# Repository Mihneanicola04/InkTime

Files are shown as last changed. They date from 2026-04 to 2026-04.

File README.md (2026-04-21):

# InkTime - Smartwatch Open Source

**InkTime** este un start-up dedicat crearii unui smartwatch accesibil si open-source. Acest repository contine documentatia tehnica, fisierele de proiectare hardware (schematica si layout PCB), fisierele de productie si modelele 3D necesare pentru fabricarea dispozitivului.

## 1. Diagrama Bloc
Diagrama de mai jos ilustreaza arhitectura sistemului, evidentiind interconexiunile dintre microcontrolerul nRF52840 si modulele periferice (Display, IMU, Alimentare).

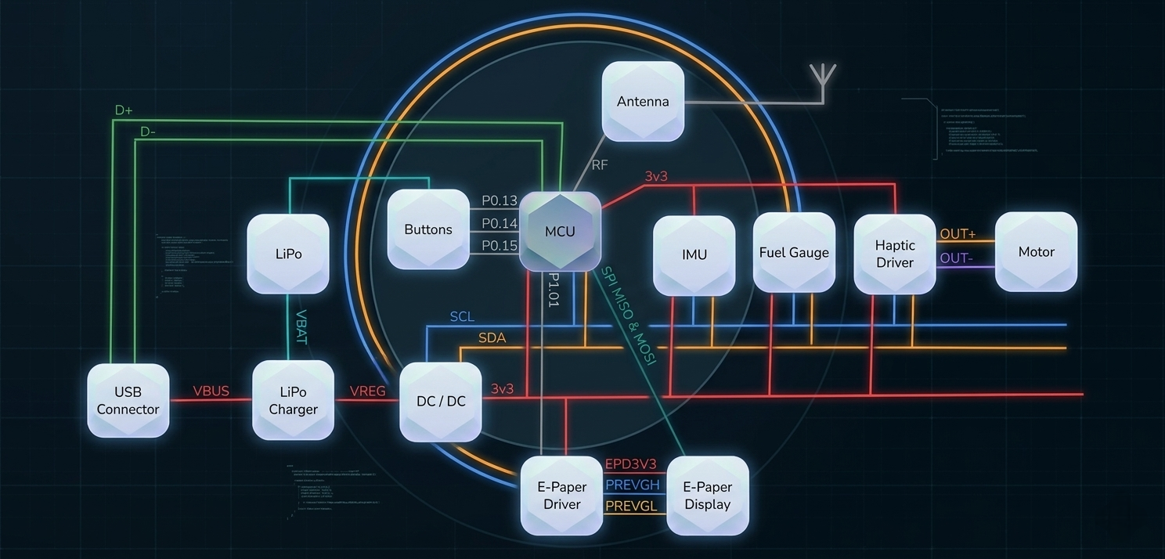
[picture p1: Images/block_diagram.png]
Diagrama Bloc
 

---

## 2. Bill of Materials (BOM)
Toate componentele au fost selectate pentru a fi compatibile cu asamblarea automata prin JLC PCB.

| Componenta / Modul | Descriere | Link Achizitie (JLC Parts) | Datasheet |
| :--- | :--- | :--- | :--- |
| **nRF52840** | SoC Bluetooth Low Energy | [Link JLC](https://jlcpcb.com/parts) | (https://infocenter.nordicsemi.com/) |
| **Display E-Paper** | Ecran cu consum redus | [Link JLC](https://jlcpcb.com/parts) |(https://jlcpcb.com/parts) |
| **Baterie Li-Po** | 3.7V, conectare directa pe pad-uri | [Link JLC](https://jlcpcb.com/parts) |(https://jlcpcb.com/parts) |
| **Senzor IMU** | Senzor de miscare (Accel/Gyro) | [Link JLC](https://jlcpcb.com/parts) | (https://jlcpcb.com/parts) |
| **Butoane SMD** | Tip 0201/0402 conform cerintelor | [Link JLC](https://jlcpcb.com/parts) |(https://jlcpcb.com/parts) |
| **Condensatoare** | 100nF (0201) / >100nF (0402) | [Link JLC](https://jlcpcb.com/parts) |(https://jlcpcb.com/parts) |

---

## 3. Functionalitate Hardware si Design

### Detalii Tehnice
* **Unitate de procesare:** nRF52840, ales pentru integrarea BLE si eficienta energetica.
* **Interfete de comunicatie:**
    * **SPI:** Utilizat pentru controlul ecranului e-paper pentru rate de refresh optime.
    * **I2C:** Utilizat pentru senzorul IMU si managementul bateriei.
* **Managementul energiei:** PCB-ul include circuite de protectie pentru bateria Li-Po. Consumul a fost optimizat prin utilizarea condensatoarelor de decuplare de 100nF amplasate imediat langa pinii de alimentare. Autonomia a fost calculata avand in vedere starea de sleep si timpii activi ai procesorului si display-ului.
* **PCB Design:** * Grosime PCB: **1mm**.
    * Trasee de putere (VCC, 3V3): **0.3mm**.
    * Trasee de date: **0.15mm**.
    * Plan de masa: Prezent pe ambele straturi (Top/Bottom) cu **Via Stitching** pentru integritatea semnalului radio.

### Mapare Pini nRF52840
| Pin nRF52840 | Componenta | Functie / Justificare |
| :--- | :--- | :--- |
| **P0.xx** | SPI CLK | Clock pentru ecranul e-paper |
| **P0.yy** | I2C SDA | Date pentru senzorul IMU |
| **P0.zz** | Buton 1 | Intrare digitala cu pull-up intern |
| **VBUS** | USB-C | Detectare alimentare si incarcare baterie |

---

## 4. Implementare si Decizii de Proiectare (Design Log)

In cadrul procesului de dezvoltare (EVT/DVT), s-au luat urmatoarele decizii tehnice:
1.  **Amplasare Componente:** Toate componentele au fost plasate pe layer-ul **TOP** pentru a simplifica procesul de fabricatie.
2.  **Antena:** A fost plasata la extremitatea placii, cu planul de masa decupat dedesubt pentru a evita atenuarea semnalului BLE.
3.  **Conectivitate Baterie:** Din ratiuni de spatiu in carcasa, s-a renuntat la conectorul JST, bateria fiind lipita direct pe test pad-urile dedicate.
4.  **Erori Acceptate:** Eroarea DRC "Only INPUT pins on NET ID" a fost ignorata conform specificatiilor, fiind un artefact al bibliotecii de simboluri.
5.  **Mecanica:** Carcasa a fost ajustata in Fusion360 pentru a asigura alinierea perfecta a portului USB-C si a butoanelor fizice.
---

## 5. Structura Repository
* `/Hardware`: Fisiere native Fusion360 (.sch, .brd).
* `/Manufacturing`: Fisiere Gerber, BOM si Pick and Place.
* `/Mechanical`: Modele 3D (STEP/Exploded view) si asamblarea in Fusion360.
* `/Images`: Randari ale produsului finit si ale PCB-ului.
---

## 6   . Licenta
Acest proiect este licentiat sub [Apache License 2.0](LICENSE).

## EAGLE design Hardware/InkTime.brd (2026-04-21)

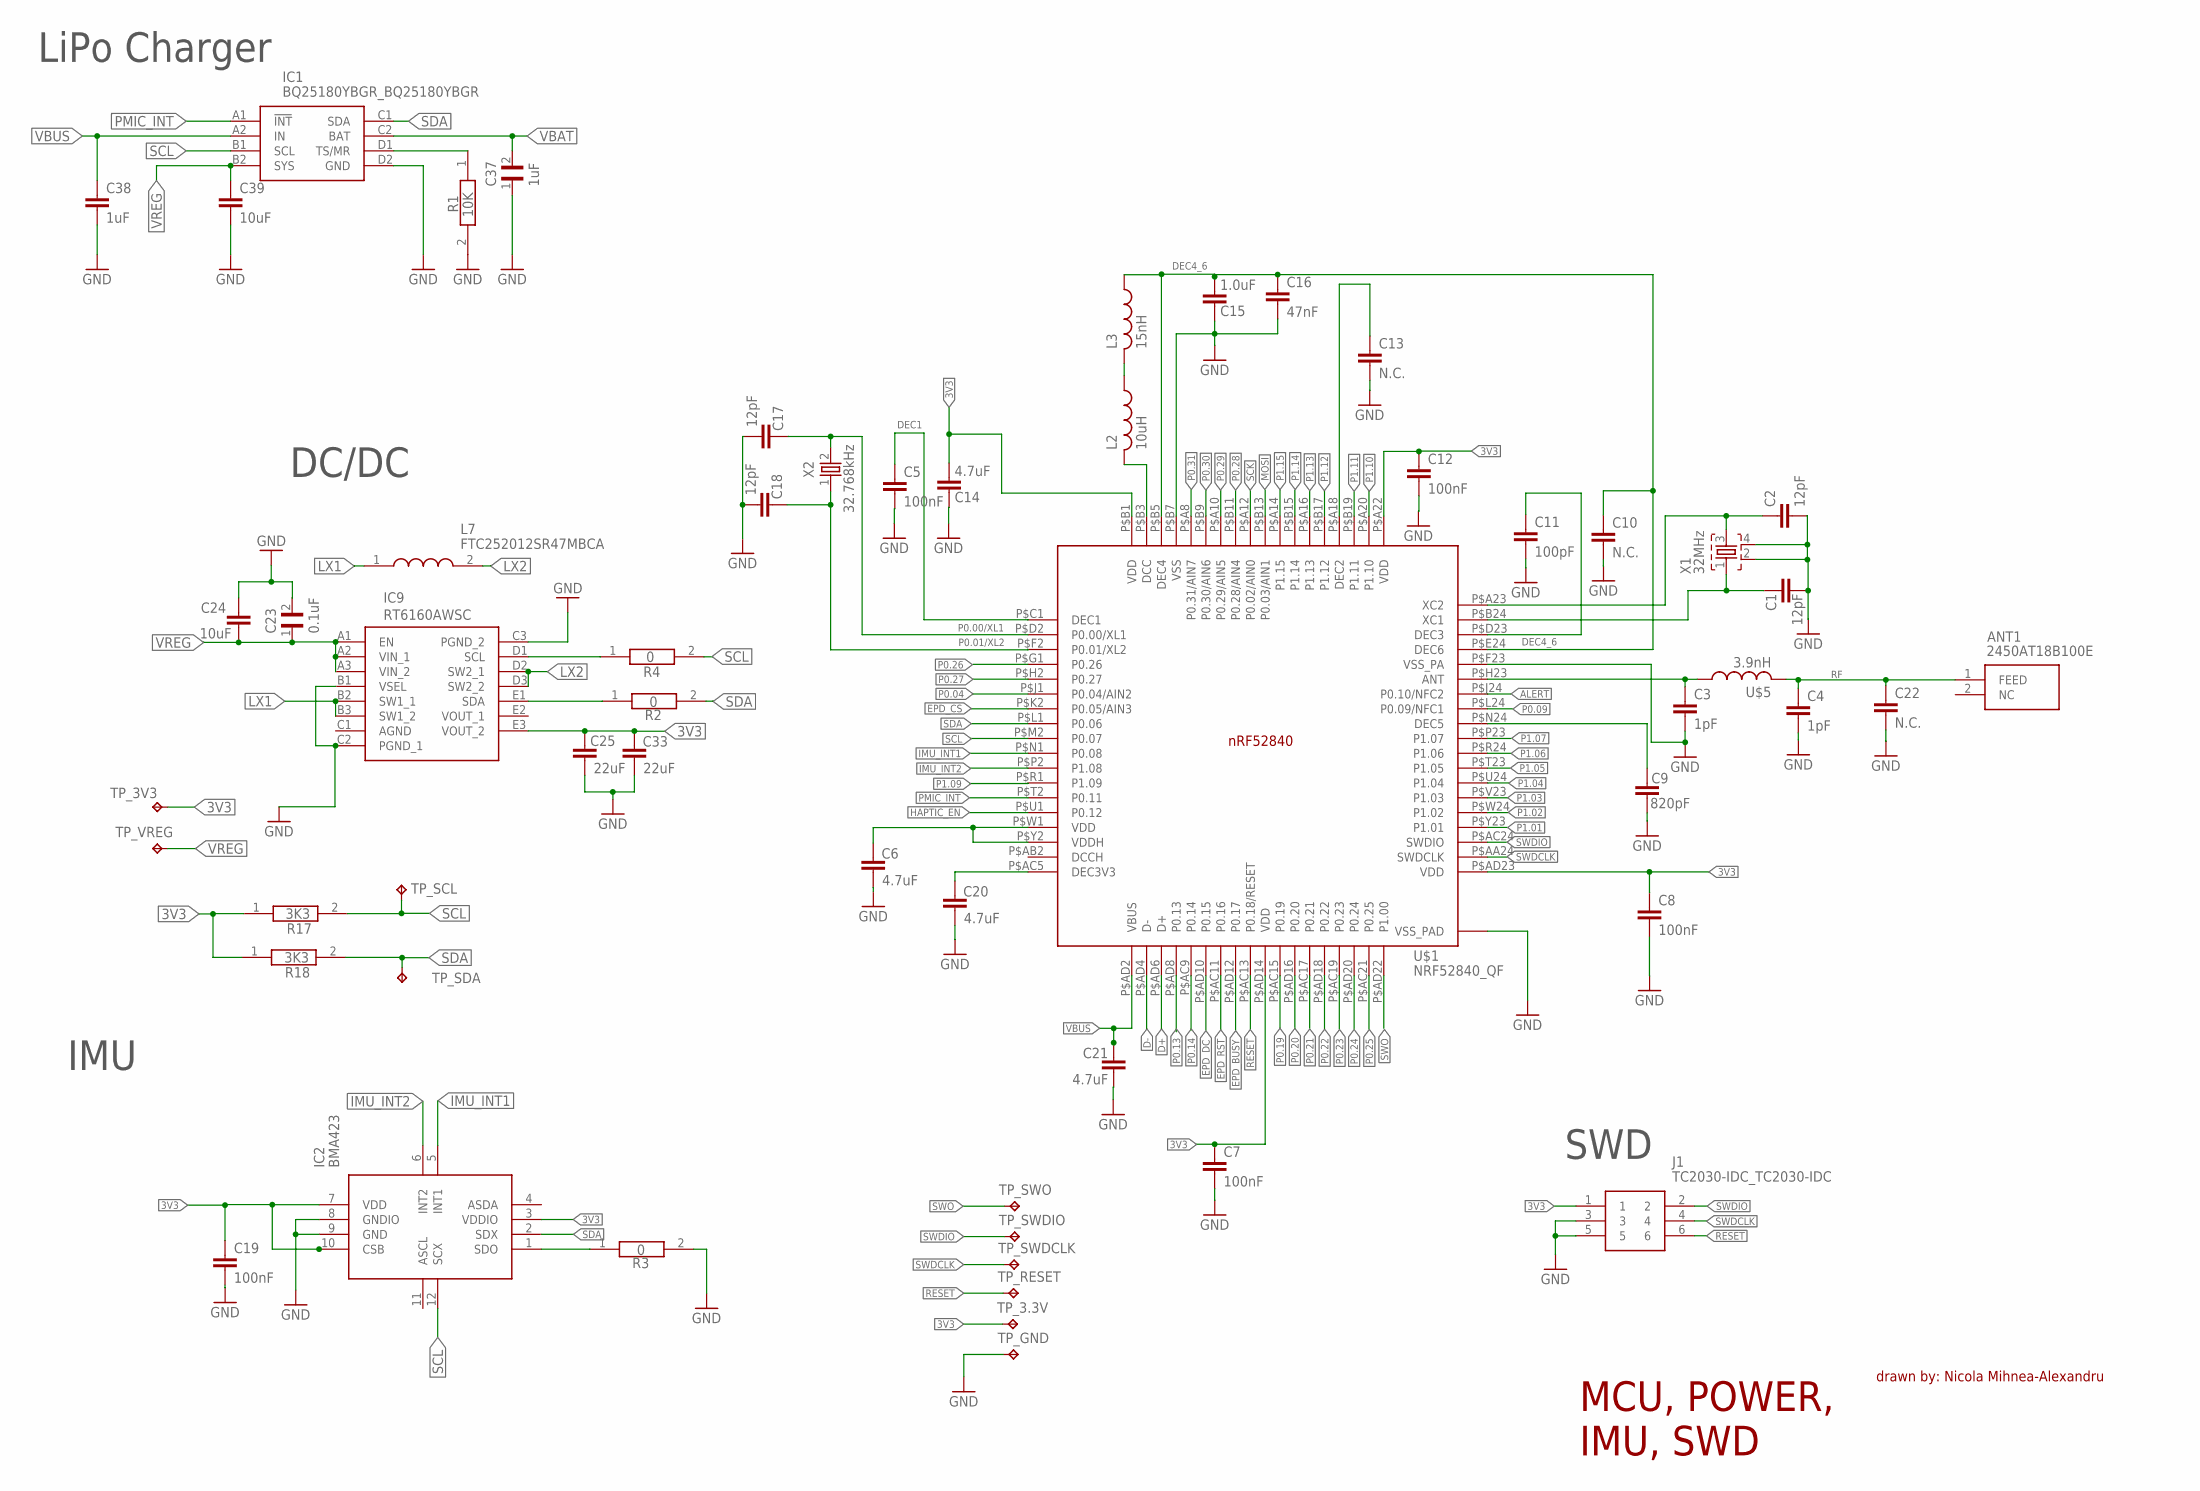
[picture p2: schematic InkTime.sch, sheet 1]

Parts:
ANT1: 2450AT18B100E; 2450AT18B100E_ANTC3216X140N
C1, C2, C17, C18: 12pF; NORDIC_NRF_3_RESC0201_N
C3, C4: 1pF; NORDIC_NRF_3_RESC0201_N
C5, C7, C8, C12, C19: 100nF; NORDIC_NRF_3_RESC0201_N
C6, C14, C20, C21: 4.7uF; NORDIC_NRF_3_RESC0402_N
C9: 820pF; NORDIC_NRF_3_RESC0201_N
C10, C13, C22: N.C.; NORDIC_NRF_3_RESC0201_N
C11: 100pF; NORDIC_NRF_3_RESC0201_N
C15: 1.0uF; NORDIC_NRF_3_RESC0402_N
C16: 47nF; NORDIC_NRF_3_RESC0201_N
C23: 0.1uF; GRM011R60J152KE01L_2_CAPC0201X13N
C24, C39: 10uF; NORDIC_NRF_3_RESC0402_N
C25, C33: 22uF; NORDIC_NRF_3_RESC0402_N
C37: 1uF; GRM011R60J152KE01L_2_CAPC0201X13N
C38: 1uF; NORDIC_NRF_3_RESC0402_N
IC1: BQ25180YBGR_BQ25180YBGR; BQ25180YBGR_BGA8C40P2X4_100X155X50
IC2: BMA423; BMA423_BMA423
IC9: RT6160AWSC; RT6160AWSC_BGA15C40P3X5_140X230X60
J1: TC2030-IDC_TC2030-IDC; TC2030-IDC_TC2030IDC
L2: 10uH; NORDIC_NRF_2_RESC0201_N
L3: 15nH; NORDIC_NRF_2_RESC0201_N
L7: FTC252012SR47MBCA; MLP2016SR47MT0S1_INDC2016X100N
R1: 10K; CPF0201D7K68C1_0201
R2, R3, R4: 0; CPF0201D7K68C1_0201
R17, R18: 3K3; CPF0201D7K68C1_0201
TP_3.3V, TP_3V3: HECTOR_WATCH_1_TPTP20R; HECTOR_WATCH_1_TP20R
TP_GND: HECTOR_WATCH_1_TPTP20R; HECTOR_WATCH_1_TP20R
TP_RESET: HECTOR_WATCH_1_TPTP20R; HECTOR_WATCH_1_TP20R
TP_SCL: HECTOR_WATCH_1_TPTP20R; HECTOR_WATCH_1_TP20R
TP_SDA: HECTOR_WATCH_1_TPTP20R; HECTOR_WATCH_1_TP20R
TP_SWDCLK: HECTOR_WATCH_1_TPTP20R; HECTOR_WATCH_1_TP20R
TP_SWDIO: HECTOR_WATCH_1_TPTP20R; HECTOR_WATCH_1_TP20R
TP_SWO: HECTOR_WATCH_1_TPTP20R; HECTOR_WATCH_1_TP20R
TP_VREG: HECTOR_WATCH_1_TPTP20R; HECTOR_WATCH_1_TP20R
U$1: NRF52840_QF; NORDIC_NRF_4_AQFN50P700X700X85_HS-74N
U$5: 3.9nH; NORDIC_NRF_2_RESC0201_N
X1: 32MHz; NORDIC_NRF_BT-XTAL_2016_N
X2: 32.768kHz; NORDIC_NRF_1_XTAL_3215_N

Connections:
3V3: C7.1, C8.1, C12.1, C14.2, C19.1, C25.1, C33.1, IC2.3 (VDDIO), IC9.E3 (VOUT_2), J1.1, R17.1, R18.1, TP_3.3V.TP, TP_3V3.TP, U$1.P$A22 (VDD), U$1.P$AD14 (VDD), U$1.P$AD23 (VDD), U$1.P$B1 (VDD); also elsewhere on the board
ALERT: U$1.P$J24 (P0.10/NFC2); also elsewhere on the board
D+: U$1.P$AD6 (D+); also elsewhere on the board
D-: U$1.P$AD4 (D-); also elsewhere on the board
DEC1: C5.1, U$1.P$C1 (DEC1)
DEC4_6: C10.1, C15.2, C16.1, L3.1, U$1.P$B5 (DEC4), U$1.P$E24 (DEC6)
EPD_BUSY: U$1.P$AD12 (P0.17); also elsewhere on the board
EPD_CS: U$1.P$K2 (P0.05/AIN3); also elsewhere on the board
EPD_DC: U$1.P$AD10 (P0.15); also elsewhere on the board
EPD_RST: U$1.P$AC11 (P0.16); also elsewhere on the board
GND: C1.2, C2.2, C3.2, C4.2, C5.2, C6.2, C7.2, C8.2, C9.2, C10.2, C11.2, C12.2, C13.2, C14.1, C15.1, C16.2, C17.2, C18.2, C19.2, C20.2, C21.2, C22.2, C23.2, C24.1, C25.2, C33.2, C37.1, C38.2, C39.2, IC1.D2 (GND), IC2.8 (GNDIO), IC2.9 (GND), IC9.B1 (VSEL), IC9.C2 (PGND_1), IC9.C3 (PGND_2), J1.3, J1.5, R1.2, R3.2, TP_GND.TP, U$1.P$74 (VSS_PAD), U$1.P$75 (VSS_PAD), U$1.P$76 (VSS_PAD), U$1.P$77 (VSS_PAD), U$1.P$78 (VSS_PAD), U$1.P$79 (VSS_PAD), U$1.P$80 (VSS_PAD), U$1.P$81 (VSS_PAD), U$1.P$82 (VSS_PAD), U$1.P$83 (VSS_PAD), U$1.P$84 (VSS_PAD), U$1.P$85 (VSS_PAD), U$1.P$86 (VSS_PAD), U$1.P$87 (VSS_PAD), U$1.P$88 (VSS_PAD), U$1.P$89 (VSS_PAD), U$1.P$90 (VSS_PAD), U$1.P$B7 (VSS), U$1.P$F23 (VSS_PA), X1.2, X1.4; also elsewhere on the board
HAPTIC_EN: U$1.P$U1 (P0.12); also elsewhere on the board
IMU_INT1: IC2.5 (INT1), U$1.P$N1 (P0.08)
IMU_INT2: IC2.6 (INT2), U$1.P$P2 (P1.08)
LX1: IC9.B2 (SW1_1), IC9.B3 (SW1_2), L7.1
LX2: IC9.D2 (SW2_1), IC9.D3 (SW2_2), L7.2
MOSI: U$1.P$B13 (P0.03/AIN1); also elsewhere on the board
unnamed: C20.1, U$1.P$AC5 (DEC3V3)
unnamed: IC9.D1 (SCL), R4.1
unnamed: IC9.E1 (SDA), R2.1
unnamed: IC1.D1 (TS/MR), R1.1
unnamed: C6.1, U$1.P$W1 (VDD)
unnamed: IC2.7 (VDD), IC2.10 (CSB)
unnamed: L2.2, U$1.P$B3 (DCC)
unnamed: L2.1, L3.2
unnamed: IC2.1 (SDO), R3.1
unnamed: C11.1, U$1.P$D23 (DEC3)
unnamed: C2.1, U$1.P$A23 (XC2), X1.3
unnamed: C13.1, U$1.P$A18 (DEC2)
unnamed: C1.1, U$1.P$B24 (XC1), X1.1
unnamed: C3.1, U$1.P$H23 (ANT), U$5.1
unnamed: C9.1, U$1.P$N24 (DEC5)
P0.00/XL1: C17.1, U$1.P$D2 (P0.00/XL1), X2.2
P0.01/XL2: C18.1, U$1.P$F2 (P0.01/XL2), X2.1
P0.04: U$1.P$J1 (P0.04/AIN2)
P0.09: U$1.P$L24 (P0.09/NFC1)
P0.13: U$1.P$AD8 (P0.13); also elsewhere on the board
P0.14: U$1.P$AC9 (P0.14); also elsewhere on the board
P0.19: U$1.P$AC15 (P0.19)
P0.20: U$1.P$AD16 (P0.20)
P0.21: U$1.P$AC17 (P0.21)
P0.22: U$1.P$AD18 (P0.22)
P0.23: U$1.P$AC19 (P0.23)
P0.24: U$1.P$AD20 (P0.24)
P0.25: U$1.P$AC21 (P0.25)
P0.26: U$1.P$G1 (P0.26)
P0.27: U$1.P$H2 (P0.27)
P0.28: U$1.P$B11 (P0.28/AIN4)
P0.29: U$1.P$A10 (P0.29/AIN5)
P0.30: U$1.P$B9 (P0.30/AIN6)
P0.31: U$1.P$A8 (P0.31/AIN7)
P1.01: U$1.P$Y23 (P1.01); also elsewhere on the board
P1.02: U$1.P$W24 (P1.02); also elsewhere on the board
P1.03: U$1.P$V23 (P1.03)
P1.04: U$1.P$U24 (P1.04)
P1.05: U$1.P$T23 (P1.05)
P1.06: U$1.P$R24 (P1.06)
P1.07: U$1.P$P23 (P1.07)
P1.09: U$1.P$R1 (P1.09)
P1.10: U$1.P$A20 (P1.10)
P1.11: U$1.P$B19 (P1.11)
P1.12: U$1.P$B17 (P1.12)
P1.13: U$1.P$A16 (P1.13)
P1.14: U$1.P$B15 (P1.14)
P1.15: U$1.P$A14 (P1.15)
PMIC_INT: IC1.A1 (!INT), U$1.P$T2 (P0.11)
RESET: J1.6, TP_RESET.TP, U$1.P$AC13 (P0.18/RESET)
RF: ANT1.1 (FEED), C4.1, C22.1, U$5.2
SCK: U$1.P$A12 (P0.02/AIN0); also elsewhere on the board
SCL: IC1.B1 (SCL), IC2.12 (SCX), R4.2, R17.2, TP_SCL.TP, U$1.P$M2 (P0.07); also elsewhere on the board
SDA: IC1.C1 (SDA), IC2.2 (SDX), R2.2, R18.2, TP_SDA.TP, U$1.P$L1 (P0.06); also elsewhere on the board
SWDCLK: J1.4, TP_SWDCLK.TP, U$1.P$AA24 (SWDCLK)
SWDIO: J1.2, TP_SWDIO.TP, U$1.P$AC24 (SWDIO)
SWO: TP_SWO.TP, U$1.P$AD22 (P1.00)
VBAT: C37.2, IC1.C2 (BAT); also elsewhere on the board
VBUS: C21.1, C38.1, IC1.A2 (IN), U$1.P$AD2 (VBUS); also elsewhere on the board
VREG: C23.1, C24.2, C39.1, IC1.B2 (SYS), IC9.A1 (EN), IC9.A2 (VIN_1), IC9.A3 (VIN_2), TP_VREG.TP

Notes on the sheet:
LiPo Charger
DC/DC
IMU
SWD
MCU, POWER, IMU, SWD
drawn by: Nicola Mihnea-Alexandru

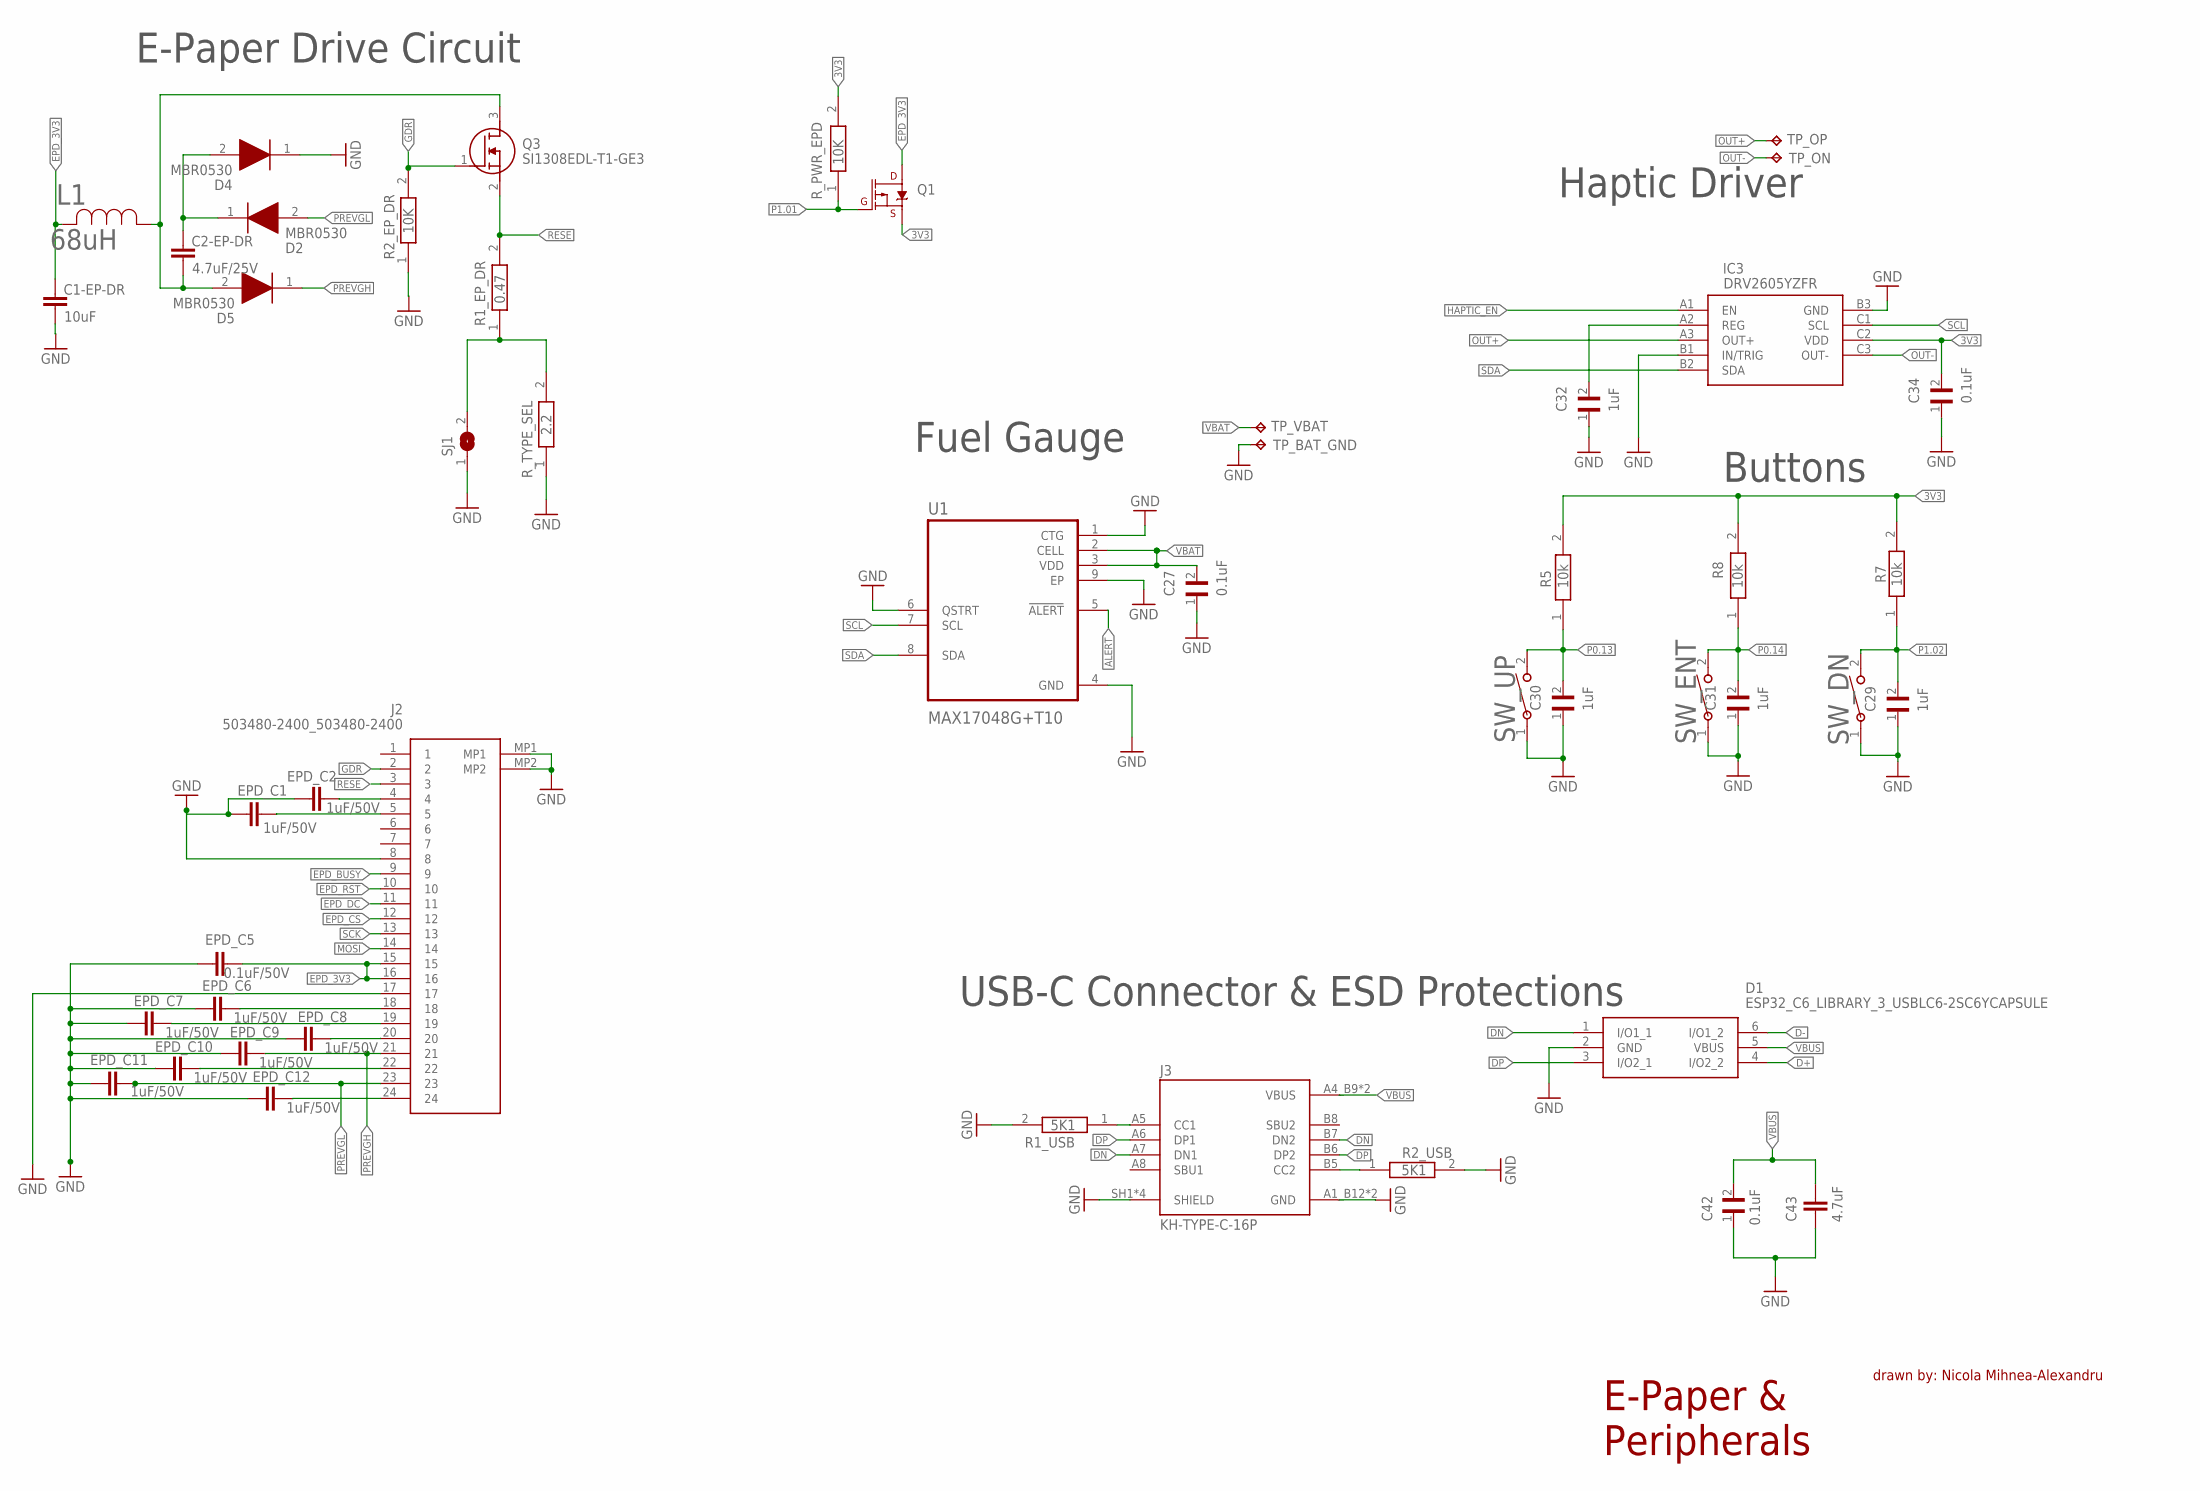
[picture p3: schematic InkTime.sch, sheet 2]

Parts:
C1-EP-DR: 10uF; NORDIC_NRF_3_RESC0402_N
C2-EP-DR: 4.7uF/25V; NORDIC_NRF_3_RESC0402_N
C27, C34, C42: 0.1uF; GRM011R60J152KE01L_2_CAPC0201X13N
C29, C30, C31, C32: 1uF; GRM011R60J152KE01L_2_CAPC0201X13N
C43: 4.7uF; NORDIC_NRF_3_RESC0402_N
D1: ESP32_C6_LIBRARY_3_USBLC6-2SC6YCAPSULE; ESP32_C6_LIBRARY_3_SOT95P280X145-6N
D2, D4, D5: MBR0530; ESP32_C6_LIBRARY_5_SOD3716X135N
EPD_C1, EPD_C2, EPD_C6, EPD_C7, EPD_C8, EPD_C9, EPD_C10, EPD_C11, EPD_C12: 1uF/50V; NORDIC_NRF_3_RESC0402_N
EPD_C5: 0.1uF/50V; NORDIC_NRF_3_RESC0402_N
IC3: DRV2605YZFR; DRV2605YZFR_BGA9C50P3X3_144X144X62
J2: 503480-2400_503480-2400; 503480-2400_5034802400
J3: KH-TYPE-C-16P; KH-TYPE-C-16P_KINGHELM_KH-TYPE-C-16P
L1: 68uH; ESP32_C6_LIBRARY_2_IND_4828-WE-TPC_WRE
Q1: ESP32_C6_LIBRARY_4_ESP32_WROVER_SPARKFUN-DISCRETE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; ESP32_C6_LIBRARY_4_ESP32_C6_LIBRARY_4_ESP32_C6_LIBRARY_4_ES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
Q3: SI1308EDL-T1-GE3; ESP32_C6_LIBRARY_6_SOT65P210X110-3N
R1_EP_DR: 0.47; CPF0201D7K68C1_0201
R1_USB, R2_USB: 5K1; CPF0201D7K68C1_0201
R2_EP_DR: 10K; CPF0201D7K68C1_0201
R5, R7, R8: 10k; CPF0201D7K68C1_0201
R_PWR_EPD: 10K; CPF0201D7K68C1_0201
R_TYPE_SEL: 2.2; CPF0201D7K68C1_0201
SJ1: ESP32_C6_LIBRARY_7_JUMPER_SJ
SW_DN: 2025-10-22_07-23-44_LIBRARY_EVP-AKE31A; 2025-10-22_07-23-44_LIBRARY_SW_EVP-AKE31A_PAN
SW_ENT: 2025-10-22_07-23-44_LIBRARY_EVP-AKE31A; 2025-10-22_07-23-44_LIBRARY_SW_EVP-AKE31A_PAN
SW_UP: 2025-10-22_07-23-44_LIBRARY_EVP-AKE31A; 2025-10-22_07-23-44_LIBRARY_SW_EVP-AKE31A_PAN
TP_BAT_GND: HECTOR_WATCH_1_TPTP20R; HECTOR_WATCH_1_TP20R
TP_ON: HECTOR_WATCH_1_TPTP20R; HECTOR_WATCH_1_TP20R
TP_OP: HECTOR_WATCH_1_TPTP20R; HECTOR_WATCH_1_TP20R
TP_VBAT: HECTOR_WATCH_1_TPTP20R; HECTOR_WATCH_1_TP20R
U1: MAX17048G+T10; ESP32_C6_LIBRARY_SON50P200X200X80-9N

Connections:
3V3: C34.2, IC3.C2 (VDD), Q1.2 (S), R5.2, R7.2, R8.2, R_PWR_EPD.2; also elsewhere on the board
ALERT: U1.5 (!ALERT); also elsewhere on the board
D+: D1.4 (I/O2_2); also elsewhere on the board
D-: D1.6 (I/O1_2); also elsewhere on the board
DN: D1.1 (I/O1_1), J3.A7 (DN1), J3.B7 (DN2)
DP: D1.3 (I/O2_1), J3.A6 (DP1), J3.B6 (DP2)
EPD_3V3: C1-EP-DR.1, EPD_C5.2, J2.15, J2.16, L1.2, Q1.3 (D)
EPD_BUSY: J2.9; also elsewhere on the board
EPD_CS: J2.12; also elsewhere on the board
EPD_DC: J2.11; also elsewhere on the board
EPD_RST: J2.10; also elsewhere on the board
GDR: J2.2, Q3.1 (G), R2_EP_DR.2
GND: C1-EP-DR.2, C27.1, C29.1, C30.1, C31.1, C32.1, C34.1, C42.1, C43.1, D1.2 (GND), D4.1 (K), EPD_C1.1, EPD_C2.1, EPD_C5.1, EPD_C6.1, EPD_C7.1, EPD_C8.1, EPD_C9.1, EPD_C10.1, EPD_C11.1, EPD_C12.1, IC3.B1 (IN/TRIG), IC3.B3 (GND), J2.8, J2.17, J2.MP1, J2.MP2, J3.A1_B12 (GND), J3.A12_B1 (GND), J3.SH1 (SHIELD), J3.SH2 (SHIELD), J3.SH3 (SHIELD), J3.SH4 (SHIELD), R1_USB.2, R2_EP_DR.1, R2_USB.2, R_TYPE_SEL.1, SJ1.1, SW_DN.1, SW_ENT.1, SW_UP.1, TP_BAT_GND.TP, U1.1 (CTG), U1.4 (GND), U1.6 (QSTRT), U1.9 (EP); also elsewhere on the board
HAPTIC_EN: IC3.A1 (EN); also elsewhere on the board
MOSI: J2.14; also elsewhere on the board
unnamed: C32.2, IC3.A2 (REG)
unnamed: C2-EP-DR.2, D5.2 (A), L1.1, Q3.3 (D)
unnamed: C2-EP-DR.1, D2.1 (K), D4.2 (A)
unnamed: EPD_C2.2, J2.4
unnamed: EPD_C1.2, J2.5
unnamed: R1_EP_DR.1, R_TYPE_SEL.2, SJ1.2
unnamed: J3.A5 (CC1), R1_USB.1
unnamed: J3.B5 (CC2), R2_USB.1
unnamed: EPD_C10.2, J2.22
unnamed: EPD_C6.2, J2.18
unnamed: EPD_C7.2, J2.19
unnamed: EPD_C8.2, J2.20
unnamed: EPD_C12.2, J2.24
OUT+: IC3.A3 (OUT+), TP_OP.TP
OUT-: IC3.C3 (OUT-), TP_ON.TP
P0.13: C30.2, R5.1, SW_UP.2; also elsewhere on the board
P0.14: C31.2, R8.1, SW_ENT.2; also elsewhere on the board
P1.01: Q1.1 (G), R_PWR_EPD.1; also elsewhere on the board
P1.02: C29.2, R7.1, SW_DN.2; also elsewhere on the board
PREVGH: D5.1 (K), EPD_C9.2, J2.21
PREVGL: D2.2 (A), EPD_C11.2, J2.23
RESE: J2.3, Q3.2 (S), R1_EP_DR.2
SCK: J2.13; also elsewhere on the board
SCL: IC3.C1 (SCL), U1.7 (SCL); also elsewhere on the board
SDA: IC3.B2 (SDA), U1.8 (SDA); also elsewhere on the board
VBAT: C27.2, TP_VBAT.TP, U1.2 (CELL), U1.3 (VDD); also elsewhere on the board
VBUS: C42.2, C43.2, D1.5 (VBUS), J3.A4_B9 (VBUS), J3.A9_B4 (VBUS); also elsewhere on the board

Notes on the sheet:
E-Paper Drive Circuit
Fuel Gauge
Haptic Driver
Buttons
USB-C Connector & ESD Protections
E-Paper & Peripherals
drawn by: Nicola Mihnea-Alexandru

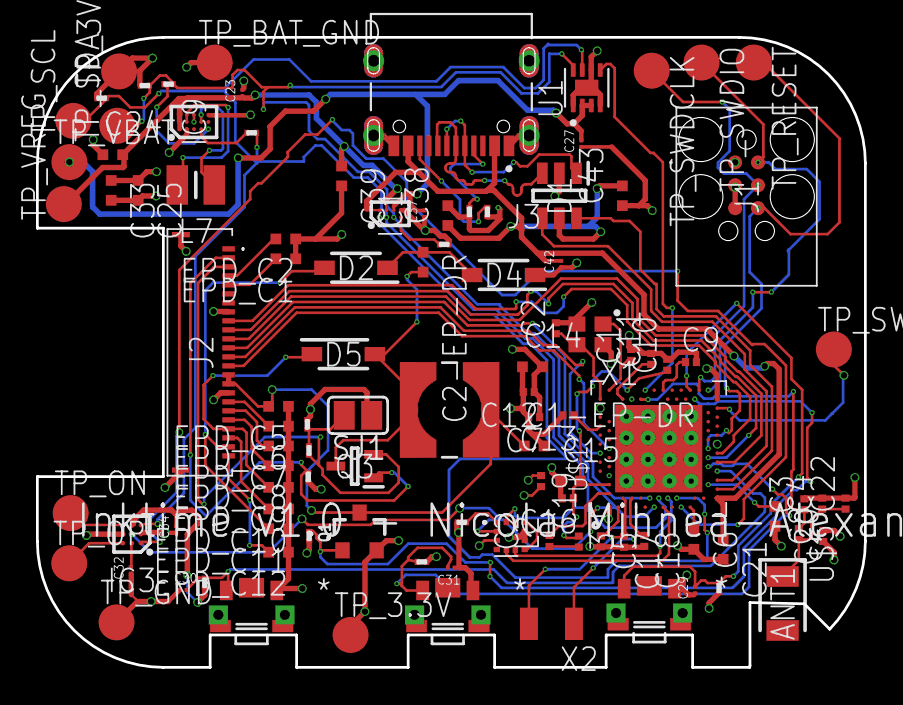
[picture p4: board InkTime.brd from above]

Board: 4 copper layers, 46.0 x 35.0 mm, 105 parts (0 on the bottom side), 72 nets.

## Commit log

2026-04-10 Added schematic
2026-04-10 Added BOM
2026-04-21 Added files after DVT review
    [InkTime.brd, InkTime.sch]

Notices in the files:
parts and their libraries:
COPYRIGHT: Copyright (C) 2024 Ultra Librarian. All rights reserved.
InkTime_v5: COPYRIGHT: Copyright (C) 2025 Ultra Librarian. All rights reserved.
